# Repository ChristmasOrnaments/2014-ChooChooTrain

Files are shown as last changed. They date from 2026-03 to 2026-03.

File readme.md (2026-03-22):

This is the second ornament in my DIY ornament series, the **Choo Choo Train**

***

This ornament is very similar to the [original 2013 ornament](https://github.com/ChristmasOrnaments/2013-Snowman), with only a few minor changes. The image in the silkscreen has changed (it's a train). The locations of the LEDs have change, and so the patterns that it produces were also changed to represent the wheels of the train in motion. Another change was to the ICSP header on the board. I made a small [pogo-pin adapter](https://github.com/timtilities/Pogo-Pin-ICSP-Adapter) so the header wouldn't take up as much room. It's much easier to use (and also easier to design board traces around). I also removed the extra LED from the back of the board, since I never used it. I had intended to use it as a "low battery" indicator, but the brightness of the LEDs does a fine job of that anyway.

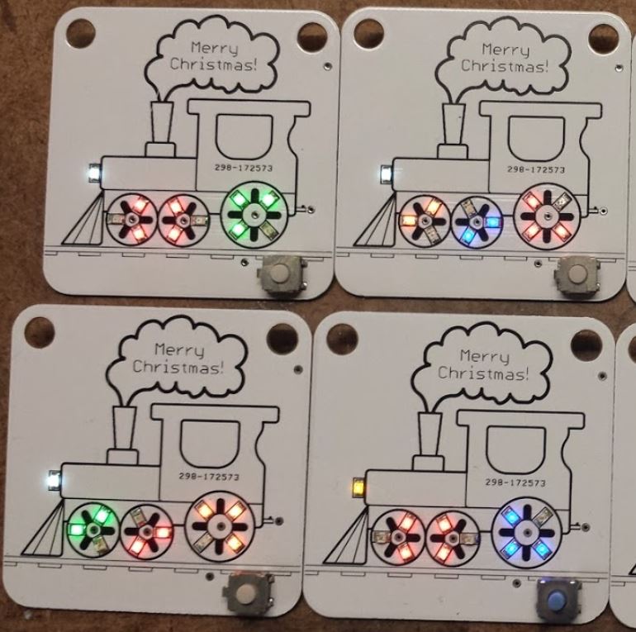
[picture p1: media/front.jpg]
Front
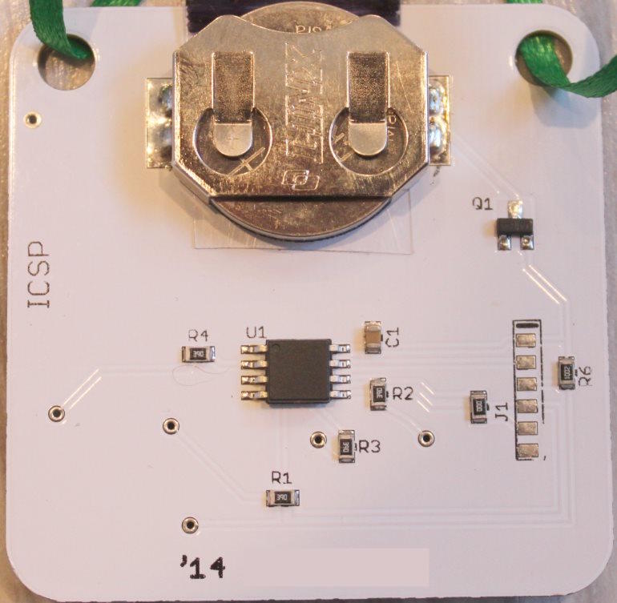
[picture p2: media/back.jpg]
back
 
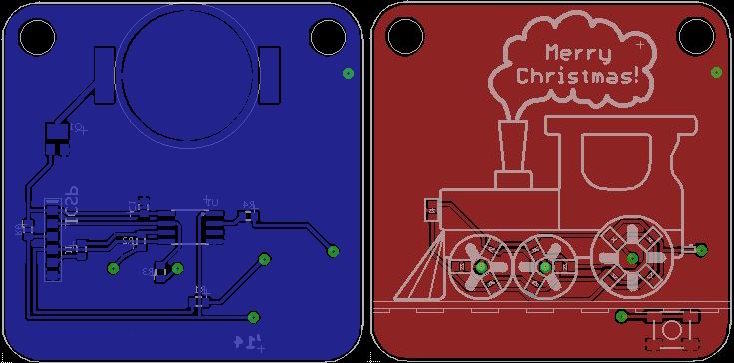
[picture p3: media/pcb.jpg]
pcb
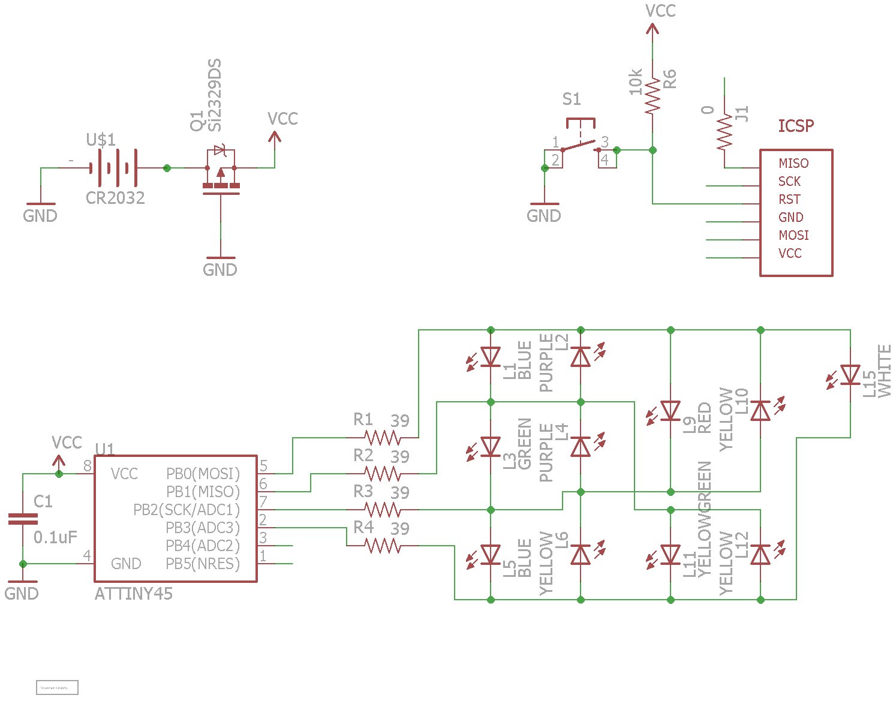
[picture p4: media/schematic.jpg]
schematic
 

The new pogo adapter:

pogo

Here's the ornament in action:
<!-- https://github.com/user-attachments/assets/bbaf6b06-1da1-494d-bd4b-d39d66976917 -->

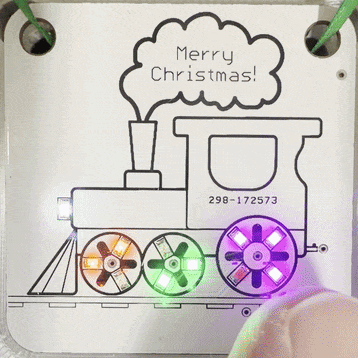
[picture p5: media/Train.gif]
Train


### Compiling

* Install [ATTinyCore](https://github.com/spencekonde/attinycore) using the boards manager
* Select **Attiny25/45/85 (No bootloader)** from the boards list
* Set the *Clock source* to **4MHz (internal)** (With newer versions, you may need to use 8MHz with a scalar variable to lower it to 4MHz)
* Set *B.O.D* to **Disabled**
* Select **Burn Bootloader** to write the changes
* Compile and write the program to the MCU

If using another method to program the MCU, just remember you need to set the fuses properly both for correct speed and for the power saving features. The fuses (for an ATTINY45) should be:

Low: C3  
High: DF  
Extended: FF

You can see the effect of different fuse settings (and their values) [here](http://www.engbedded.com/fusecalc/).

### Resources

**Charlieplexing Code using a byte array:**  
[https://www.instructables.com/CharliePlexed-LED-string-for-the-Arduino/](https://www.instructables.com/CharliePlexed-LED-string-for-the-Arduino/)

**Battery calculator:**  
[http://oregonembedded.com/batterycalc.htm](http://oregonembedded.com/batterycalc.htm)

**Power saving information:**  
[http://www.gammon.com.au/forum/?id=11497](http://www.gammon.com.au/forum/?id=11497)  
[http://www.insidegadgets.com/2011/02/05/reduce-attiny-power-consumption-by-sleeping-with-the-watchdog-timer](http://www.insidegadgets.com/2011/02/05/reduce-attiny-power-consumption-by-sleeping-with-the-watchdog-timer/)  
[http://www.nongnu.org/avr-libc/user-manual/group\_\_avr\_\_power.html](http://www.nongnu.org/avr-libc/user-manual/group__avr__power.html)

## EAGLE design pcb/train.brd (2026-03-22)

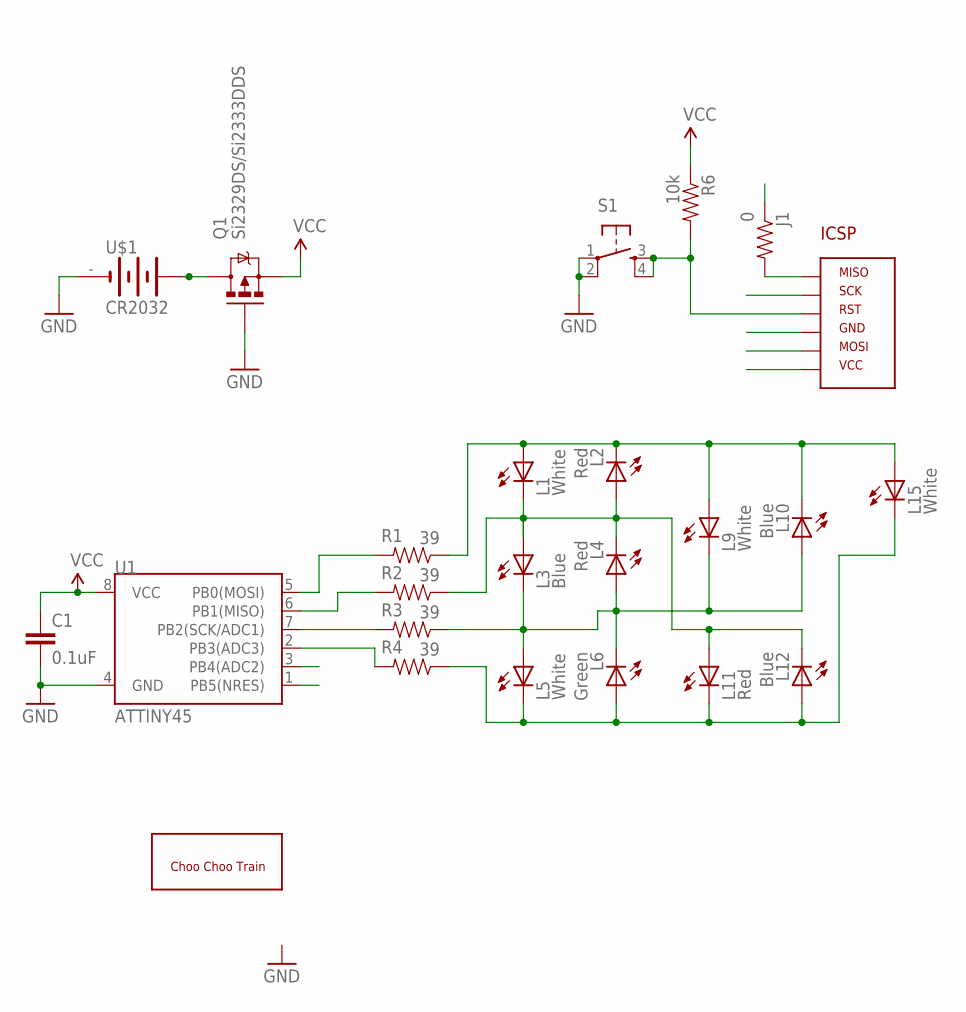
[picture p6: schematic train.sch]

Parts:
C1: 0.1uF; 0805
J1: 0; 0805
L1, L5: White; LED-0805-RED
L2, L4: Red; LED-0805-RED
L3, L12: Blue; LED-0805-RED
L6: Green; LED-0805-BLUE
L9: White; LED-0805-YELLOW
L10: Blue; LED-0805-BLUE
L11: Red; LED-0805-BLUE
L15: White; LED-0805-BLUE
Q1: Si2329DS/Si2333DDS; SOT23-3
R1, R2, R3, R4: 39; 0805
R6: 10k; 0805
S1: TAC_SWITCHSMD; TACTILE_SWITCH_SMD
U1: ATTINY45; SO08-EIAJ
U$1: CR2032; BAT-HLD-001
U$2: AVR_ICSP_6P1X6; AVR_ICSP_1X6_SMD
U$3: 5X6_CHOOCHOOTRAIN; CHOOCHOO

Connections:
GND: C1.2, Q1.1 (G), S1.1, S1.2, U1.4 (GND), U$1.-, U$2.P6 (GND)
L12: L1.C, L2.A, L3.A, L4.C, L11.A, L12.C, R2.1
MISO: J1.1, R2.2, U1.6 (PB1(MISO))
MOSI: R1.2, U1.5 (PB0(MOSI)), U$2.P4 (MOSI)
unnamed: Q1.3 (D), U$1.+@1 (+), U$1.+@2 (+)
unnamed: L3.C, L4.A, L5.A, L6.C, L9.C, L10.A, R3.1
unnamed: R4.2, U1.2 (PB3(ADC3))
unnamed: L1.A, L2.C, L9.A, L10.C, L15.A, R1.1
unnamed: J1.2, U$2.P5 (MISO)
unnamed: L5.C, L6.A, L11.C, L12.A, L15.C, R4.1
RST: R6.2, S1.3, S1.4, U1.1 (PB5(NRES)), U$2.P3 (RST)
SCK: R3.2, U1.7 (PB2(SCK/ADC1)), U$2.P2 (SCK)
VCC: C1.1, Q1.2 (S), R6.1, U1.8 (VCC), U$2.P1 (VCC)

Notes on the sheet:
ICSP

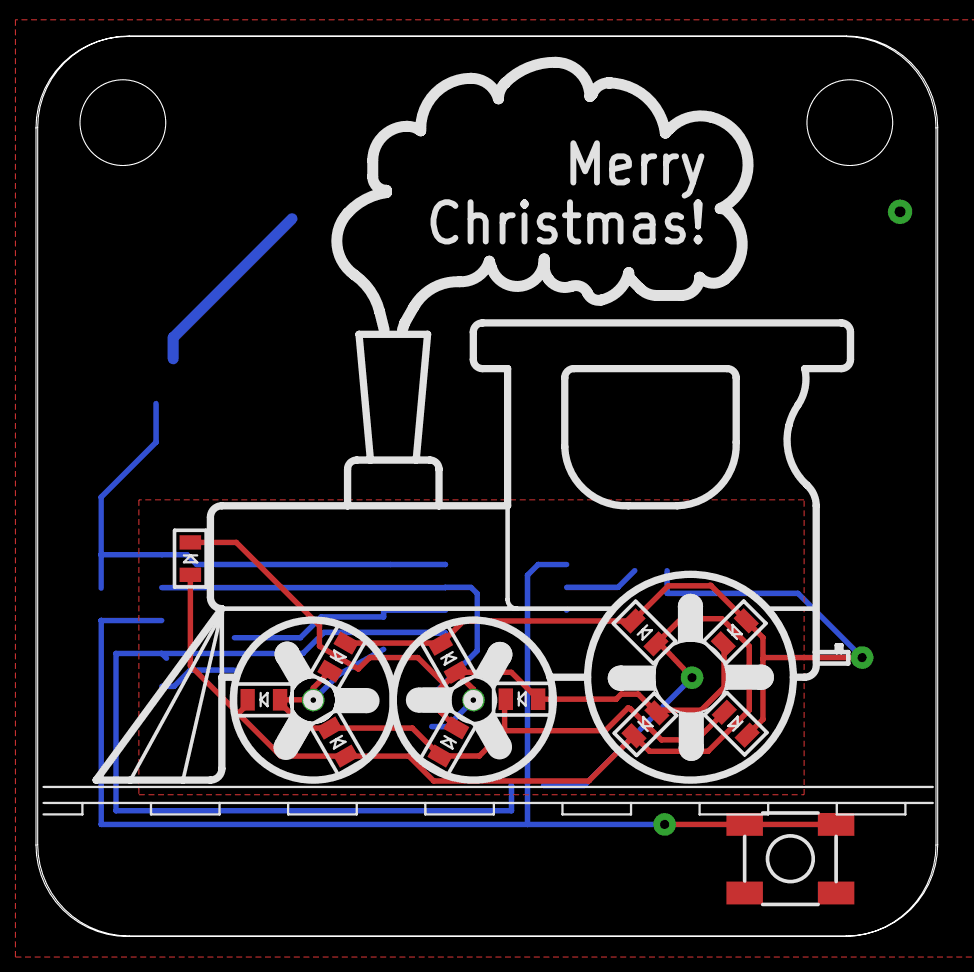
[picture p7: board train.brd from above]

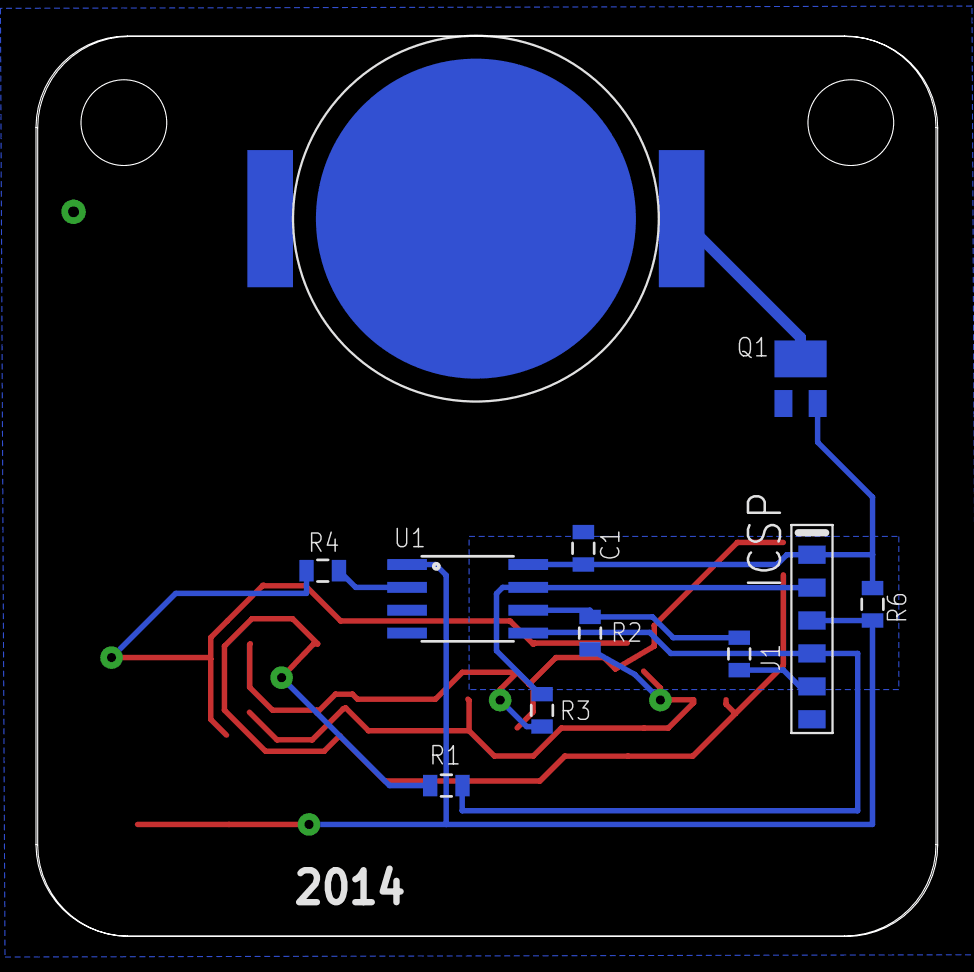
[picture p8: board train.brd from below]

Board: 2 copper layers, 50.0 x 50.0 mm, 24 parts (11 on the bottom side), 13 nets.

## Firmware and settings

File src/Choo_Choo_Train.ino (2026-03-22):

/*
 * ATTiny85_Internal_8MHz_Template.cpp
 *
 * Created: 6/28/2013 6:12:11 PM
 * Charlieplexing functions modeled after the code found here:
 *	 http://www.instructables.com/id/CharliePlexed-LED-string-for-the-Arduino/step7/Coding-the-Arduino/
 */ 

#ifdef F_CPU  
#undef F_CPU
#endif  
#define F_CPU 4000000 // 4 MHz

// ATMEL ATTINY85 / ARDUINO
//
//                            ____
//         (D5/A0) RST/PB5  1|*   |8  VCC
//   PWM   (D3/A3)     PB3  2|    |7  PB2  (D2/A1)
//   PWM   (D4/A2)     PB4  3|    |6  PB1  (D1)     PWM
//                     GND  4|____|5  PB0  (D0)     PWM


#include <avr/pgmspace.h>
// Power Mgt:
#include <avr/sleep.h>
#include <avr/wdt.h>

// FUNCTION PROTOTYPES
void displayChar(int from, int through, int tranSpeed); // loads a Pattern from above. From & through specify what patterns to show. tranSpeed is the speed of the frames
//void ledSpecify(int highPin, int lowPin); // This allows you to manually control which pin goes low & which one goes high
void turnon(int led); // This turns on a certian led from the list of leds
void alloff(); // This turns all the LED's off
void setup_watchdog(int ii);
void system_sleep();

// ******************************************************************************************************************
//
// Much of the charlieplex code has been modified from http://www.instructables.com/id/CharliePlexed-LED-string-for-the-Arduino/step7/Coding-the-Arduino/
// The power management code is from 

#define LEDCount 11
byte pins[4];
//const byte LEDCount = 20;

// The attiny85 watchdog only sleeps for 8 seconds at a time, so for a longer period of time we need to setup a counter variable
//   and check that against the # of times it wakes up.
// The internal clock isn't very accurate, so you need to factor that in. My tests show a deviation of ~0.9198 at 900 seconds,
//   so a rough equation would be [ SleepTime = DesiredTime * 0.9198 ]
// Every MCU will be different, so some experimentation will be necessary if you want accurate intervals
// Some example times:
//   5:00 -> 276
//  10:00 -> 552
//  15:00 -> 828
//  30:00 -> 1656
int SleepTime = 416; // Sleep time in seconds

int SleepCnt = SleepTime/8; // counter for watchdog wake timer

// blinkdelay is used by displayChar to set the microseconds the LED will be on, then off. It can affect brightness, but mostly affects speed
// blinkdelay could be replaced with a timeOn and timeOff to facilitate a type of PWM to increase LED brightness at low voltage 
//      (using a small Rs at higher voltage would be bad for LED unless turn-on time can be limited with this)
int blinkdelay = 50;   //Speed Param 1: smaller = faster
// runSpeed is the number of times displayChar will loop through each pattern before going to the next. Again, this affects speed
byte runSpeed = 50;      //Speed Param 2: smaller = faster (0-255) - this can be set individually when calling displayChar()

#ifndef cbi
#define cbi(sfr, bit) (_SFR_BYTE(sfr) &= ~_BV(bit))
#endif
#ifndef sbi
#define sbi(sfr, bit) (_SFR_BYTE(sfr) |= _BV(bit))
#endif
volatile boolean f_wdt = 1;

const byte LEDConnections[LEDCount][2] ={   // This stores which outputs the LEDs are connected to: { Anode, Cathode }
// Bottom Row
       { 0 , 1 },    //X1
       { 1 , 2 },    //X3
       { 2 , 3 },    //X5
       // Row 1
       { 1 , 0 },    //X2            
       { 2 , 1 },    //X4
       { 3 , 2 },    //X6
       // Row 2
       { 0 , 2 },    //X9
       { 1 , 3 },    //X11
       // Row 3
       { 2 , 0 },    //X10
       { 3 , 1 },    //X12
       // Row 4
       { 0 , 3 }    //X15
};

const byte displays[][LEDCount] PROGMEM ={  // This stores the array in Flash ROM.

// All Off (0)
    {0,0,0,0,0,0,0,0,0,0,0},

// All On (1)
    {1,1,1,1,1,1,1,1,1,1,1},

 // All LEDs Flash (2-3)
    {1,1,1,1,1,1,1,1,1,1,1},
    {0,0,0,0,0,0,0,0,0,0,0},

// Rotate Wheels, and head light (4-15)
/*    {0,1,0,1,1,1,1,1,1,1,0},
    {1,0,1,1,1,1,1,1,0,0,1},
    {1,1,1,0,0,1,1,0,1,1,1},
    {0,1,0,1,1,0,1,1,1,1,1},
    {1,0,1,1,1,1,1,1,1,0,0},
    {1,1,1,0,0,1,1,1,0,1,1},
    {0,1,0,1,1,1,1,0,1,1,1},
    {1,0,1,1,1,0,1,1,1,0,1},
    {1,1,1,0,0,1,1,1,1,1,0},
    {0,1,0,1,1,1,1,1,0,1,1},
    {1,0,1,1,1,1,1,0,1,0,1},
    {1,1,1,0,0,0,1,1,1,1,1}, */
    
// 2 off, 4 on (small), 2 off, 2 on (big) [4-15]  
    {0,1,0,1,1,1,1,1,0,1,1},
    {1,0,1,1,1,1,1,0,1,0,1},
    {1,1,1,0,0,0,1,1,1,1,1},
    {0,1,0,1,1,1,1,1,1,1,0},
    {1,0,1,1,1,1,1,1,0,0,1},
    {1,1,1,0,0,1,1,0,1,1,1},
    {0,1,0,1,1,0,1,1,1,1,1},
    {1,0,1,1,1,1,1,1,1,0,0},
    {1,1,1,0,0,1,1,1,0,1,1},
    {0,1,0,1,1,1,1,0,1,1,1},
    {1,0,1,1,1,0,1,1,1,0,1},
    {1,1,1,0,0,1,1,1,1,1,0},
    
// 1 off, 5 on (small), 1 off 3 on (big)  [16-27]
    {0,1,1,1,1,1,1,1,0,1,1},
    {1,0,1,1,1,1,1,0,1,1,1},
    {1,1,1,1,0,0,1,1,1,1,1},
    {1,1,0,1,1,1,1,1,1,1,0},
    {1,1,1,1,1,1,1,1,0,0,1},
    {1,1,1,0,1,1,1,0,1,1,1},
    {0,1,1,1,1,0,1,1,1,1,1},
    {1,0,1,1,1,1,1,1,1,1,0},
    {1,1,1,1,0,1,1,1,0,1,1},
    {1,1,0,1,1,1,1,0,1,1,1},
    {1,1,1,1,1,0,1,1,1,0,1},
    {1,1,1,0,1,1,1,1,1,1,0},

// [REVERSED] 1 off, 5 on (small), 1 off 3 on (big)  [28-39]
    {1,1,1,0,1,1,1,1,1,1,0},
    {1,1,1,1,1,0,1,1,1,0,1},
    {1,1,0,1,1,1,1,0,1,1,1},
    {1,1,1,1,0,1,1,1,0,1,1},
    {1,0,1,1,1,1,1,1,1,1,0},
    {0,1,1,1,1,0,1,1,1,1,1},
    {1,1,1,0,1,1,1,0,1,1,1},
    {1,1,1,1,1,1,1,1,0,0,1},
    {1,1,0,1,1,1,1,1,1,1,0},
    {1,1,1,1,0,0,1,1,1,1,1},
    {1,0,1,1,1,1,1,0,1,1,1},
    {0,1,1,1,1,1,1,1,0,1,1},

// [REVERSED] 2 off, 4 on (small), 2 off, 2 on (big) [40-51]
    {0,1,0,1,1,1,1,1,0,1,1},
    {1,1,1,0,0,1,1,1,1,1,0},
    {1,0,1,1,1,0,1,1,1,0,1},
    {0,1,0,1,1,1,1,0,1,1,1},
    {1,1,1,0,0,1,1,1,0,1,1},
    {1,0,1,1,1,1,1,1,1,0,0},
    {0,1,0,1,1,0,1,1,1,1,1},
    {1,1,1,0,0,1,1,0,1,1,1},
    {1,0,1,1,1,1,1,1,0,0,1},
    {0,1,0,1,1,1,1,1,1,1,0},
    {1,1,1,0,0,0,1,1,1,1,1},
    {1,0,1,1,1,1,1,0,1,0,1},

// Blink headlight [52-53]
    {0,0,0,0,0,0,1,0,0,0,0},
    {0,0,0,0,0,0,0,0,0,0,0},

};

void setup()   {        
	// initialize the digital pin as an output:
	pins[0] = 0;
	pins[1] = 1;
	pins[2] = 2;
	pins[3] = 3;

	// Status LED
    pinMode(4, OUTPUT);

	setup_watchdog(9); // Watchdog timer; approximately 8 seconds sleep
}

void loop()                     
{
	if (f_wdt==1) {  // wait for timed out watchdog / flag is set when a watchdog timeout occurs

		f_wdt=0;       // reset flag
		if (SleepCnt >= (SleepTime/8)) {
			SleepCnt = 0; // Reset sleep counter
			
// Code to execute after we wake from sleep:

			// [REVERSED] 2 off, 4 on (small), 2 off, 2 on (big)
			for (int loop=0; loop<6; loop++) {
				displayChar(40,51, 30); 
			}

			// Blink them all  
			//for (int loop=0; loop<3; loop++) {
			//	displayChar(2,3, runSpeed); 
			//}

// End of wake code

			//pinMode(0,INPUT); // Normally you would set the pinMode to INPUT to save power, but since the charlieplexing code does this, we don't need to here
			system_sleep();
			//pinMode(0,OUTPUT); // Set the pinmode back to OUTPUT, as it was before	
		} else {
			SleepCnt++;
			//pinMode(0,INPUT); // Normally you would set the pinMode to INPUT to save power, but since the charlieplexing code does this, we don't need to here
			system_sleep();
			//pinMode(0,OUTPUT); // Set the pinmode back to OUTPUT, as it was before
		}
  }	
}

// Charlieplexing Code
// *********************************************************************************************

// Courtesy of "copmutergeek"
// http://www.instructables.com/id/CharliePlexed-LED-string-for-the-Arduino/step7/Coding-the-Arduino/
void displayChar(int from, int through, int tranSpeed)// loads a Pattern from above. From & through specify what patterns to show. tranSpeed is the speed of the frames (smaller=faster)
{
  boolean run = true;
  byte k;
  int t = from;
  while(run == true)
  {
    for(int i = 0; i < tranSpeed; i++)
    {
      for(int j = 0; j < LEDCount; j++)
      {
        k = pgm_read_byte(&(displays[t][j]));
        if (k == 2)
        {
          run = false;
        }
        else if(k == 1)
        {
          turnon(j);
          delayMicroseconds(blinkdelay);
          alloff();
        }
        else if(k == 0)
        {
          delayMicroseconds(blinkdelay);
        }
      }
    }
    if(through == t){
      return;
    }
    t++;
  }
}

void turnon(int led) // This turns on a certian led from the list of leds
{
//  int pospin = LEDConnections[led][0] + 2;  //  <-- what is the +2 for?
//  int negpin = LEDConnections[led][1] + 2;
  int anode = LEDConnections[led][0];
  int cathode = LEDConnections[led][1];
  pinMode (anode, OUTPUT);
  digitalWrite (anode, HIGH);
  pinMode (cathode, OUTPUT);
  digitalWrite (cathode, LOW);
}

void alloff() // This turns all the LED's off
// TM - added sizeof(pins) to determine pin count (instead of hard-coded counts)
{
  for(int i = 0; i < sizeof(pins); i++)
  {
    pinMode (pins[i], INPUT);
  }
}

// Power Management
// *********************************************************************************************

// set system into the sleep state
// system wakes up when watchdog is timed out
void system_sleep() {
	cbi(ADCSRA,ADEN);                    // switch Analog to Digitalconverter OFF

	set_sleep_mode(SLEEP_MODE_PWR_DOWN); // sleep mode is set here
	sleep_enable();

	sleep_mode();                        // System sleeps here

	sleep_disable();                     // System continues execution here when watchdog timed out
	sbi(ADCSRA,ADEN);                    // switch Analog to Digitalconverter ON
}

// 0=16ms, 1=32ms,2=64ms,3=128ms,4=250ms,5=500ms
// 6=1 sec,7=2 sec, 8=4 sec, 9= 8sec
void setup_watchdog(int ii) {

	byte bb;
	int ww;
	if (ii > 9 ) ii=9;
	bb=ii & 7;
	if (ii > 7) bb|= (1<<5);
	bb|= (1<<WDCE);
	ww=bb;

	MCUSR &= ~(1<<WDRF);
	// start timed sequence
	WDTCR |= (1<<WDCE) | (1<<WDE);
	// set new watchdog timeout value
	WDTCR = bb;
	WDTCR |= _BV(WDIE);
}

// Watchdog Interrupt Service / is executed when watchdog timed out
ISR(WDT_vect) {
	f_wdt=1;  // set global flag
}

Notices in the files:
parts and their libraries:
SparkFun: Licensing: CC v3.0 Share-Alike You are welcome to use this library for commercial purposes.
